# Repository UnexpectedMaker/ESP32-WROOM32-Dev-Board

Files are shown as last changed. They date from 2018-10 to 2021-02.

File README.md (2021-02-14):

# ESP32-WROOM32-Dev-Board
I decided a while back that I wanted to design, build and open source a WROOM32 ESP32 development board that was designed to plug a 2.1mm 5V power supply directly into it to drive high loads like hundreds of SK6812B's or 64x32 RGB Matrix Panels.

My revision 2 board works great, but uses a fairly expensive FT231XS FTDI USB Serial chip, so I thought I'd try to redesign it to use a cheap CH340C USB chip that has a built in oscillator to reduce parts.

My aim was to drive the CH340C from 3.3V and not 5V, and the data sheets suggests this is possible, but from my experience, it’s a terrible implementation.

So I have 2x CH340C folders…
Rev4 - CH340C driven from 3.3V
Rev5 - CH340C driven from 5V

Feel free to give the 3.3V version a whirl and if you can get ti working, please let me know how!

Anyway, this was just an experiment and it’s been a fun and frustrating journey, but I learnt a lot doing this and I’ve learnt stacks more since starting this project, so it’s time to let the files out into the wild so others can have a play with them. 

Enjoy!

# Support Unexpected Maker

I love designing, making and releasing my projects as open source. I do it because I believe it’s important to share knowledge and give back to the community, like many have done before me. It helps us all learn and grow.

That said, a lot of time, effort and finances have gone into designing and releasing these files, so please consider supporting me by buying some of my products:

https://unexpectedmaker.com/shop

https://www.tindie.com/stores/seonr/

Or by becoming a Patron:

https://www.patreon.com/unexpectedmaker

# Join my discord server
https://discord.com/invite/xAHpApP

# Unexpected Maker
https://unexpectedmaker.com

http://youtube.com/unexpectedmaker

http://twitter.com/unexpectedmaker

https://www.facebook.com/unexpectedmaker/

https://www.instagram.com/unexpectedmaker/

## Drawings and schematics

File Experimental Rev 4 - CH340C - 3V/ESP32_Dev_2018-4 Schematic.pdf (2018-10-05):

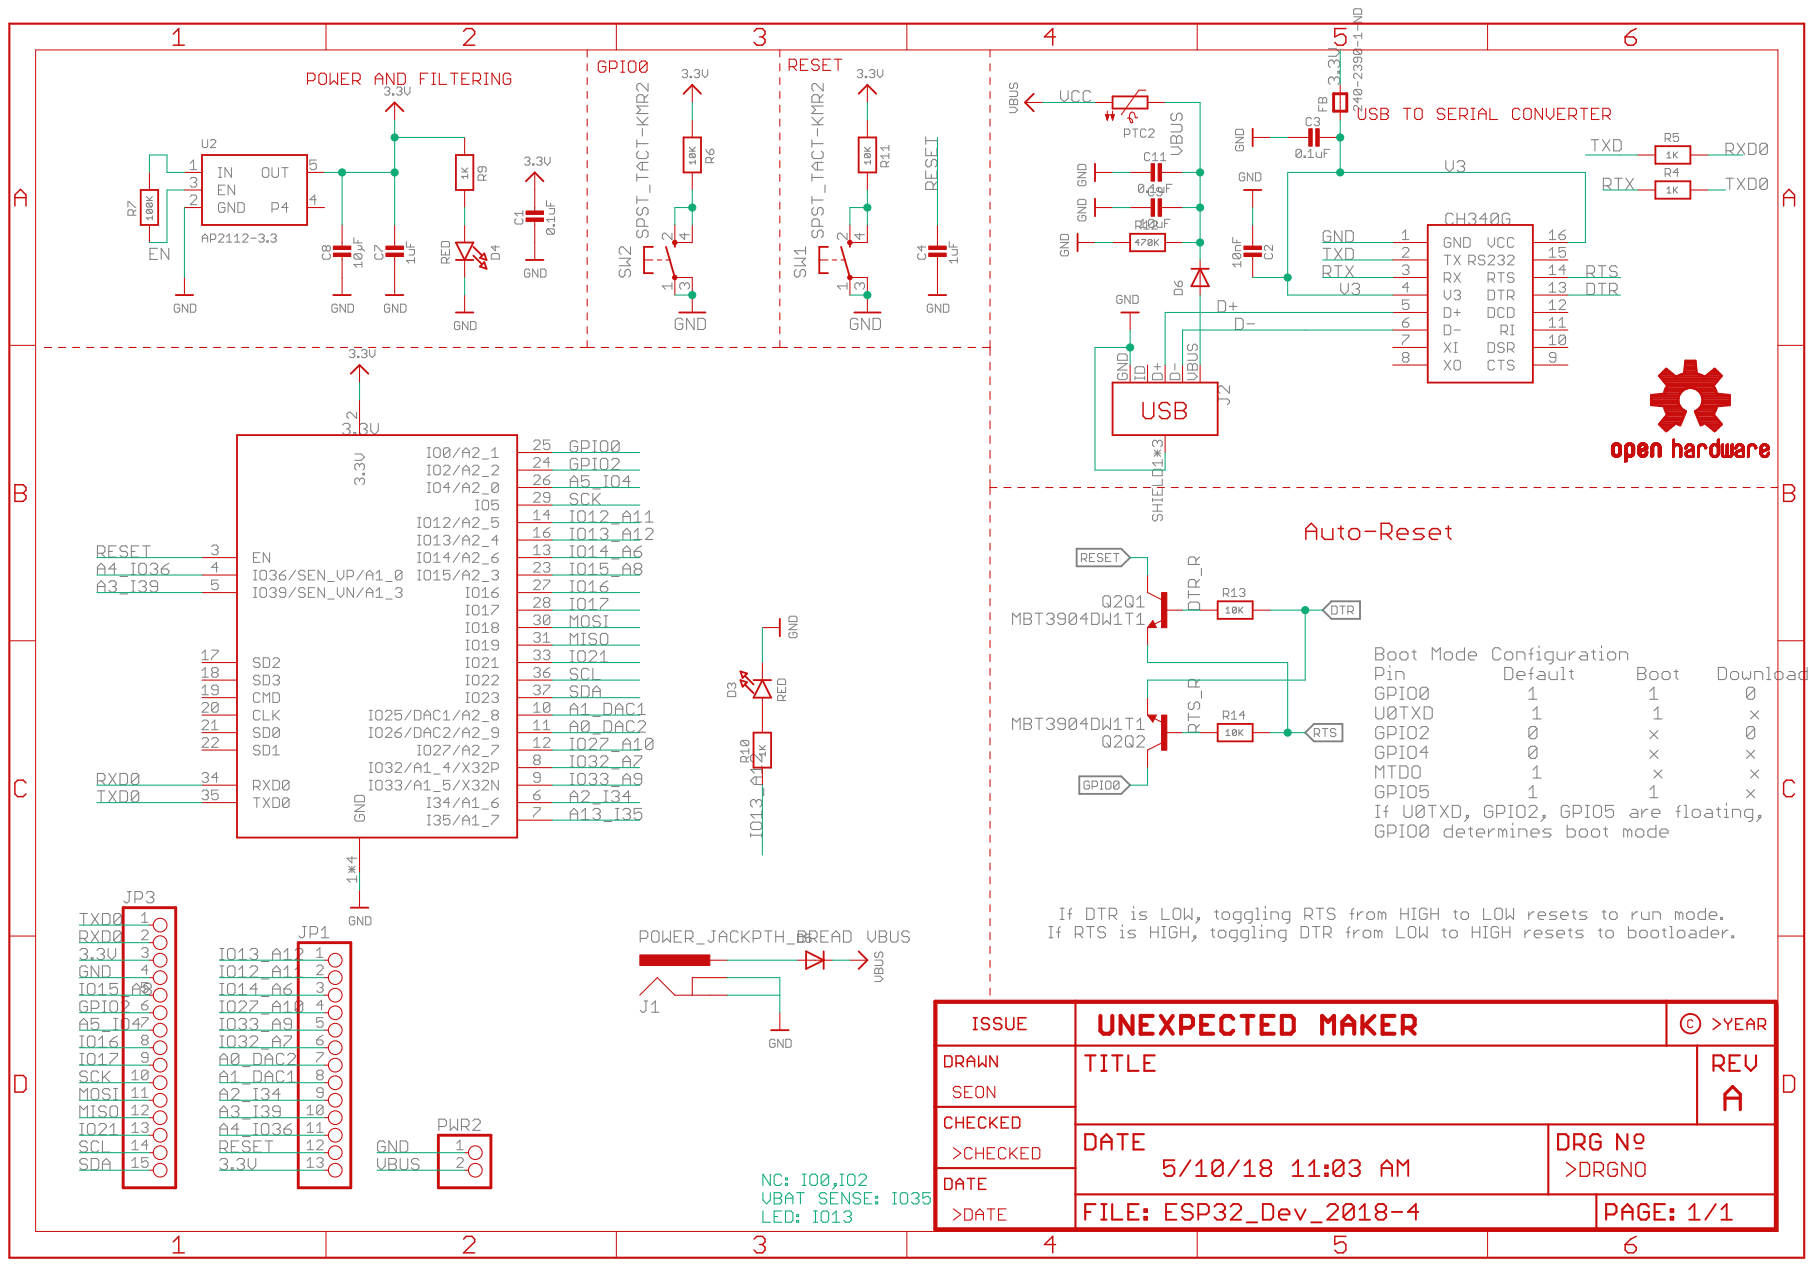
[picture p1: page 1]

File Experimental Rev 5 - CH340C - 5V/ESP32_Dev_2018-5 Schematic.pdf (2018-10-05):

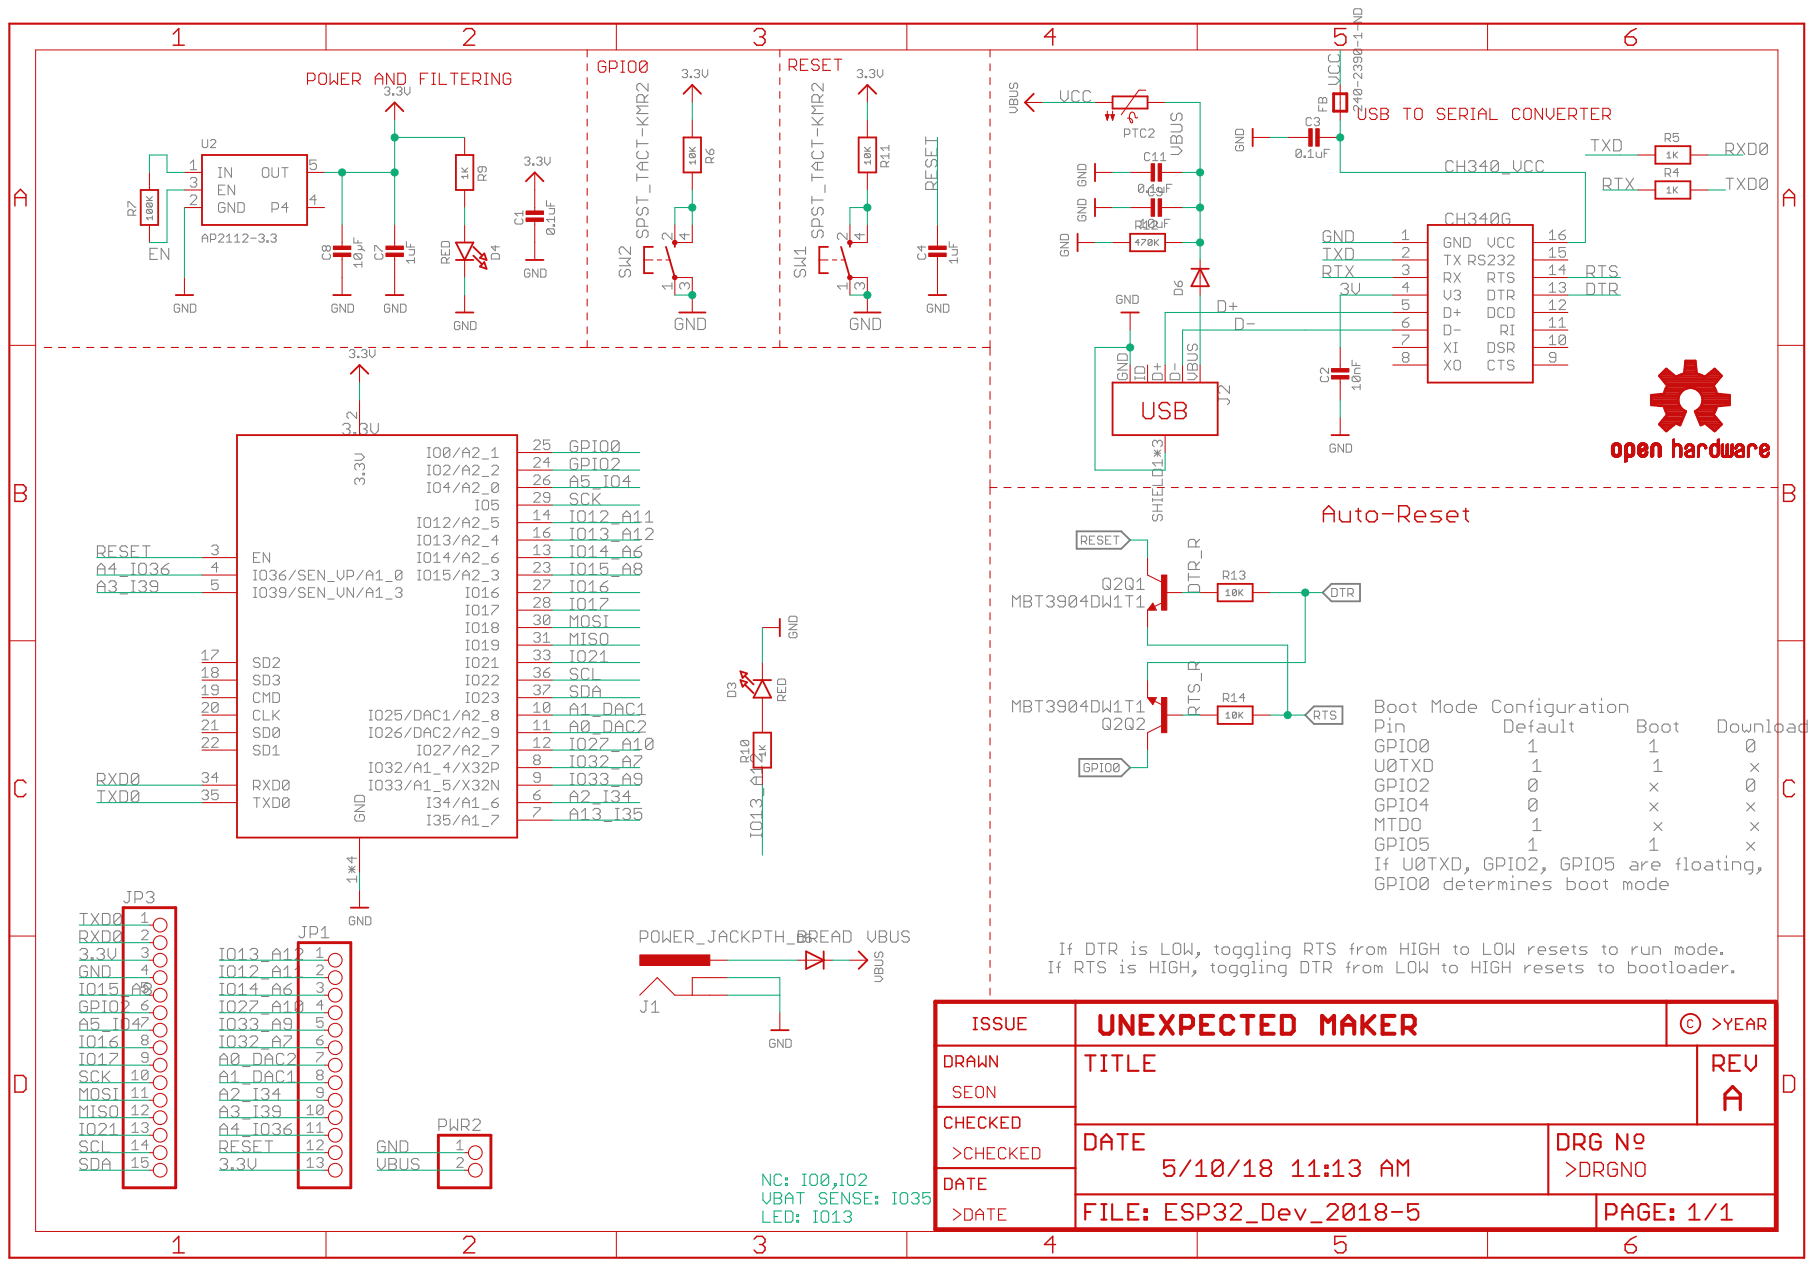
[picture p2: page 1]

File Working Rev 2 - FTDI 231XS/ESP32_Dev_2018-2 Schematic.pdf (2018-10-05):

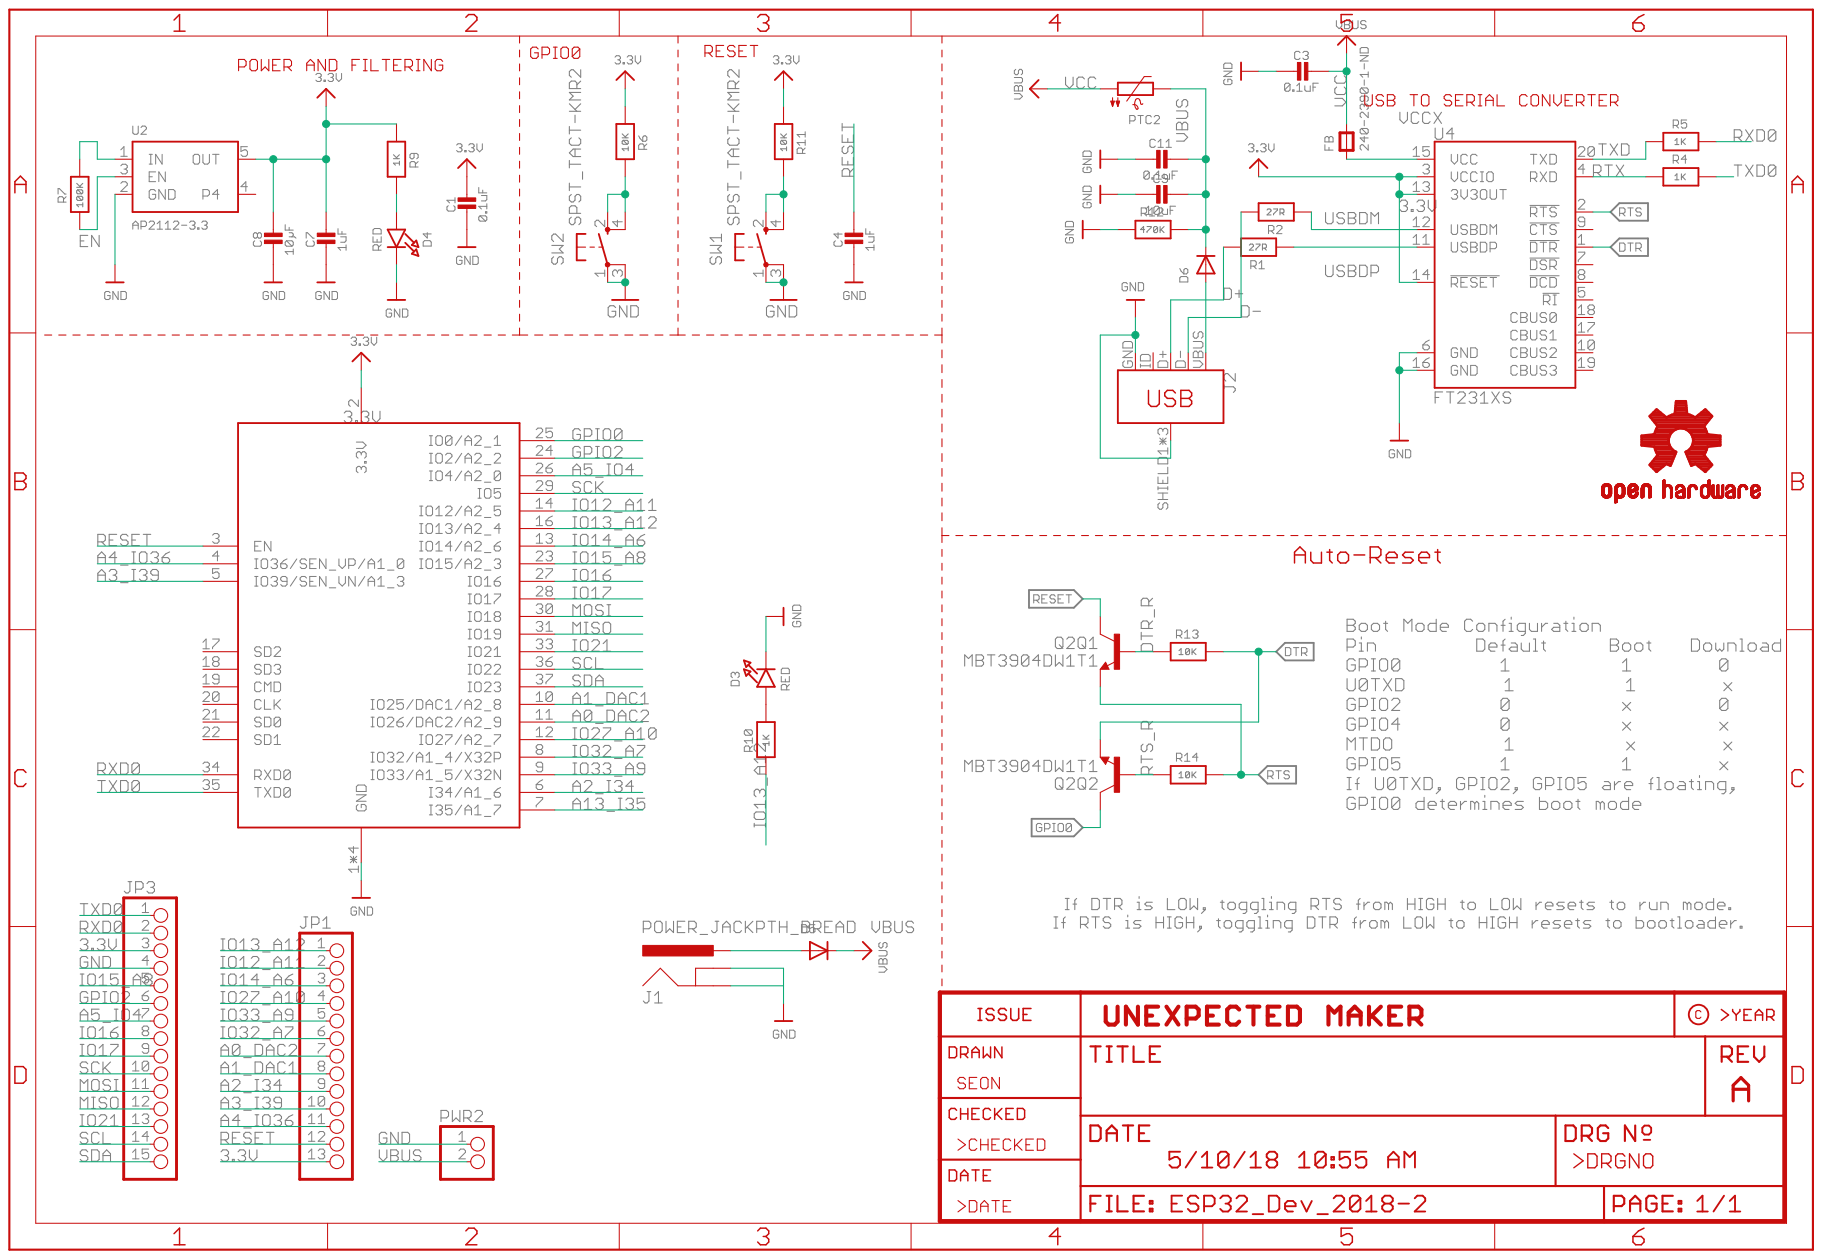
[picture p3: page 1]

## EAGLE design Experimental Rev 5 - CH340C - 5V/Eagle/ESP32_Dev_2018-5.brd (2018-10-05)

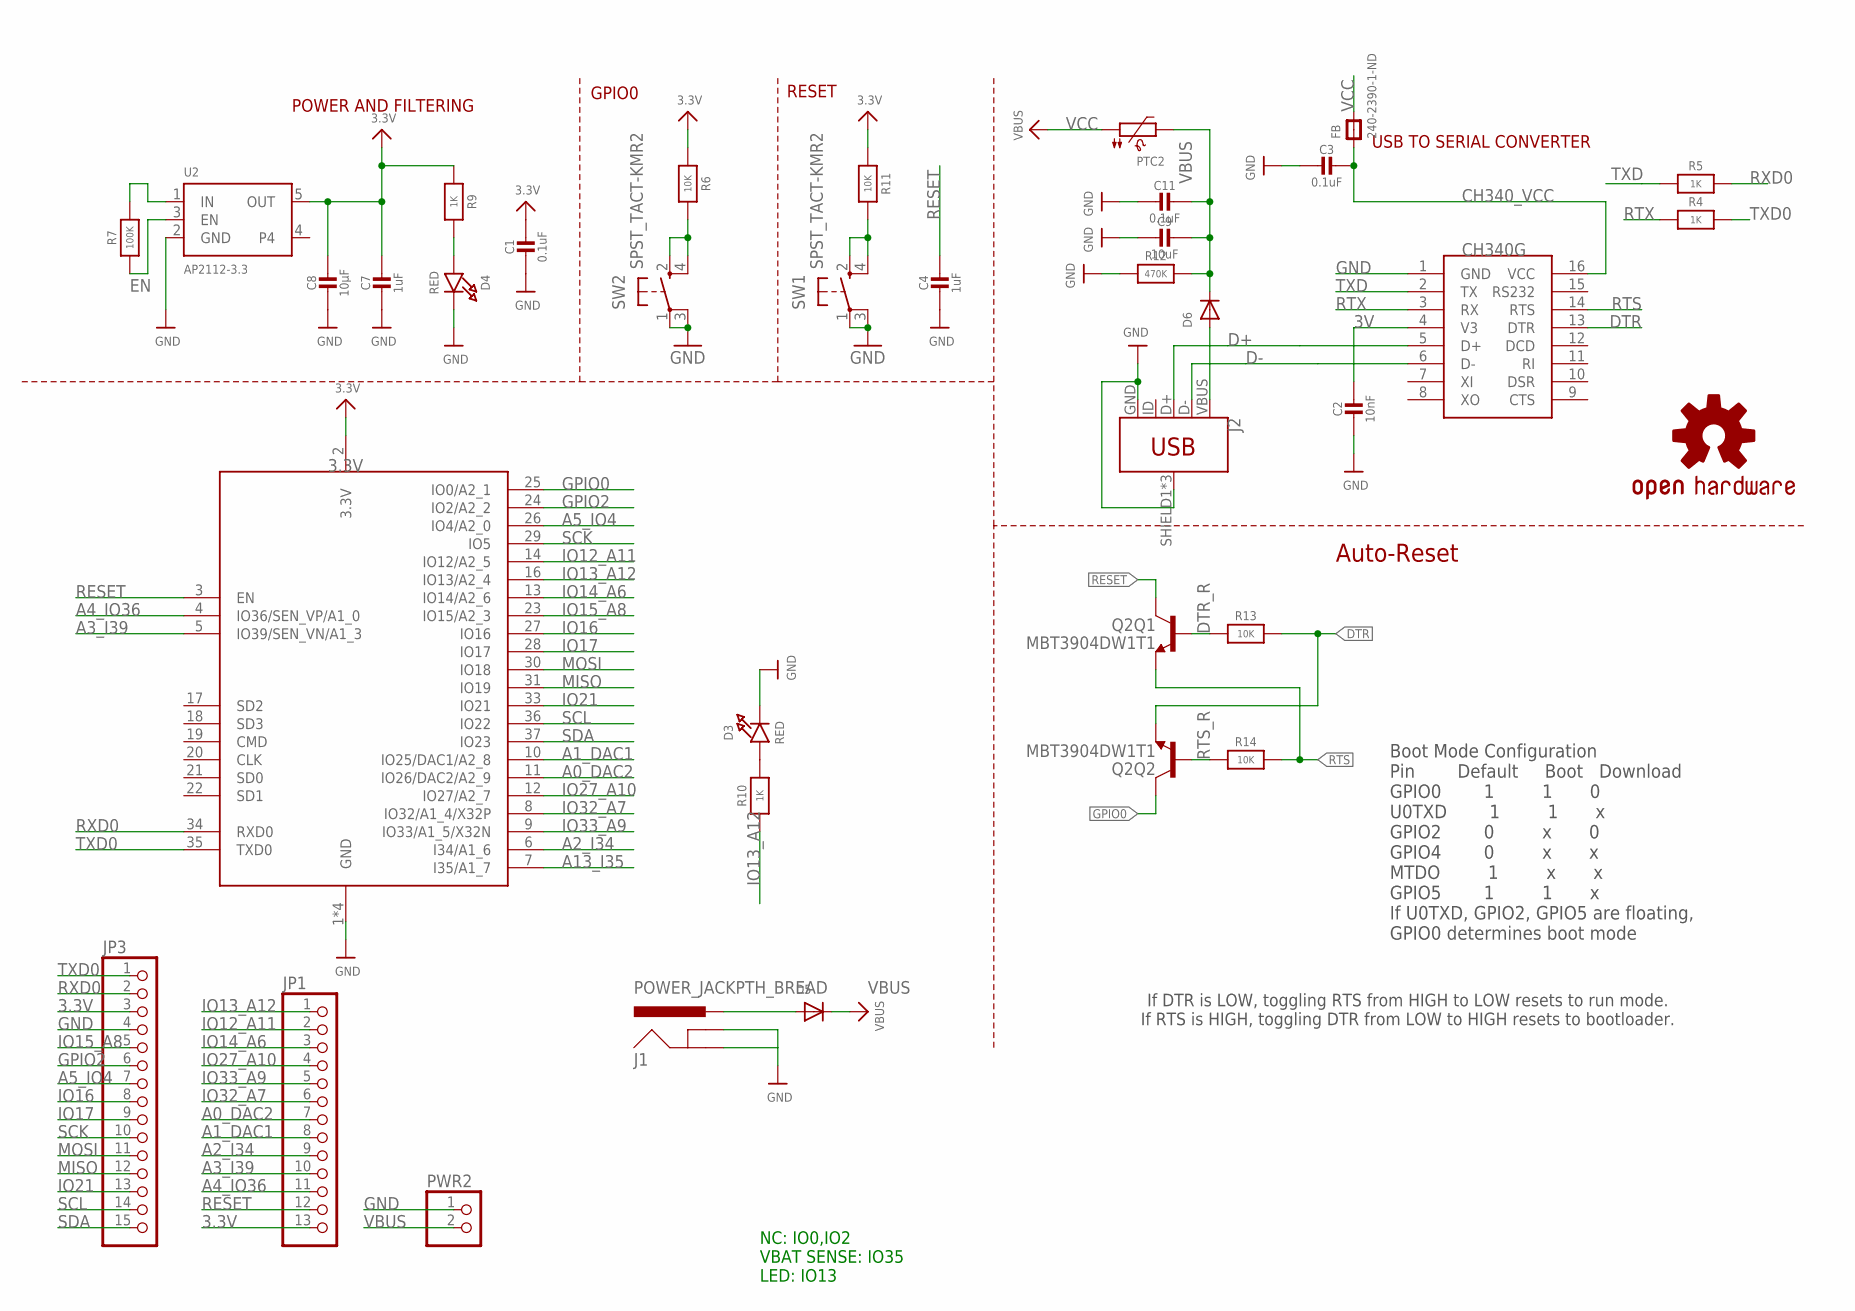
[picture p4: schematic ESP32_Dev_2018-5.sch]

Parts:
C1, C3, C11: 0.1uF; 0805-NO
C2: 10nF; 0805-NO
C4, C7: 1uF; 0805-NO
C8: 10µF; 0805-NO
C9: 10uF; 0805-NO
CH340C: CH340C; SOIC16
D3, D4: RED; CHIPLED_0805_NOOUTLINE
D5, D6: DIODESOD-123; SOD-123
FB: 240-2390-1-ND; _0805
J1: POWER_JACKPTH_BREAD; POWER_JACK_PTH_BREAD
J2: USB_MICRO-BREDUCED_PASTE; USB-B-MICRO-SMD_RED_PASTE
JP1: HEADER-1X13; 1X13_ROUND_70
JP3: HEADER-1X15; 1X15_ROUND_70
LOGO1: OSHW-LOGOM; OSHW-LOGO-M
PTC2: PTC1206; 1206
PWR2: HEADER-1X2ROUND; 1X02_ROUND
Q2: MBT3904DW1T1; SC70-6
R4, R5, R9, R10: 1K; 0805-NO
R6, R11, R13, R14: 10K; 0805-NO
R7: 100K; 0805-NO
R12: 470K; 0805-NO
SW1, SW2: SPST_TACT-KMR2; KMR2
U2: AP2112-3.3; SOT23-5
X2: ESP32_WROOM32; WROOM32

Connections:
3.3V: C1.1, C7.1, C8.1, JP1.13, JP3.3, R6.1, R9.1, R11.1, U2.5 (OUT), X2.2 (3.3V)
3V: C2.1, CH340C.4 (V3)
A0_DAC2: JP1.7, X2.11 (IO26/DAC2/A2_9)
A1_DAC1: JP1.8, X2.10 (IO25/DAC1/A2_8)
A2_I34: JP1.9, X2.6 (I34/A1_6)
A3_I39: JP1.10, X2.5 (IO39/SEN_VN/A1_3)
A4_IO36: JP1.11, X2.4 (IO36/SEN_VP/A1_0)
A5_IO4: JP3.7, X2.26 (IO4/A2_0)
A13_I35: X2.7 (I35/A1_7)
CH340_VCC: C3.1, CH340C.16 (VCC), FB.1
D+: CH340C.5 (D+), J2.D+
D-: CH340C.6 (D-), J2.D-
DTR: CH340C.13 (DTR), Q2.1 (E), R13.2
DTR_R: Q2.5 (B), R13.1
EN: R7.1, U2.3 (EN)
GND: C1.2, C2.2, C3.2, C4.2, C7.2, C8.2, C9.2, C11.2, CH340C.1 (GND), D3.C, D4.C, J1.GND, J1.GNDBREAK, J2.GND, J2.SHIELD1 (SHIELD), J2.SHIELD2 (SHIELD), J2.SHIELD3 (SHIELD), JP3.4, PWR2.1, R12.1, SW1.1, SW1.3 (P1), SW2.1, SW2.3 (P1), U2.2 (GND), X2.1 (GND), X2.15 (GND), X2.38 (GND), X2.P$1 (GND)
GPIO0: Q2.6 (C), R6.2, SW2.2 (S), SW2.4 (S1), X2.25 (IO0/A2_1)
GPIO2: JP3.6, X2.24 (IO2/A2_2)
IO12_A11: JP1.2, X2.14 (IO12/A2_5)
IO13_A12: JP1.1, R10.1, X2.16 (IO13/A2_4)
IO14_A6: JP1.3, X2.13 (IO14/A2_6)
IO15_A8: JP3.5, X2.23 (IO15/A2_3)
IO16: JP3.8, X2.27 (IO16)
IO17: JP3.9, X2.28 (IO17)
IO21: JP3.13, X2.33 (IO21)
IO27_A10: JP1.4, X2.12 (IO27/A2_7)
IO32_A7: JP1.6, X2.8 (IO32/A1_4/X32P)
IO33_A9: JP1.5, X2.9 (IO33/A1_5/X32N)
MISO: JP3.12, X2.31 (IO19)
MOSI: JP3.11, X2.30 (IO18)
unnamed: D6.A, J2.VBUS
unnamed: D3.A, R10.2
unnamed: D4.A, R9.2
RESET: C4.1, JP1.12, Q2.3 (C), R11.2, SW1.2 (S), SW1.4 (S1), X2.3 (EN)
RTS: CH340C.14 (RTS), Q2.4 (E), R14.2
RTS_R: Q2.2 (B), R14.1
RTX: CH340C.3 (RX), R4.1
RXD0: JP3.2, R5.2, X2.34 (RXD0)
SCK: JP3.10, X2.29 (IO5)
SCL: JP3.14, X2.36 (IO22)
SDA: JP3.15, X2.37 (IO23)
TXD: CH340C.2 (TX), R5.1
TXD0: JP3.1, R4.2, X2.35 (TXD0)
VBUS: C9.1, C11.1, D5.C, D6.C, PTC2.2, PWR2.2, R12.2
VBUS1: D5.A, J1.PWR
VCC: FB.2, PTC2.1, R7.2, U2.1 (IN)

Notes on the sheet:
POWER AND FILTERING
RESET
USB TO SERIAL CONVERTER
NC: IO0,IO2 VBAT SENSE: IO35 LED: IO13
Boot Mode Configuration Pin Default Boot Download GPIO0 1 1 0 U0TXD 1 1 x GPIO2 0 x 0 GPIO4 0 x x MTDO 1 x x GPIO5 1 1 x If U0TXD, GPIO2, GPIO5 are floating, GPIO0 determines boot mode
Auto-Reset
If DTR is LOW, toggling RTS from HIGH to LOW resets to run mode. If RTS is HIGH, toggling DTR from LOW to HIGH resets to bootloader.
GPIO0

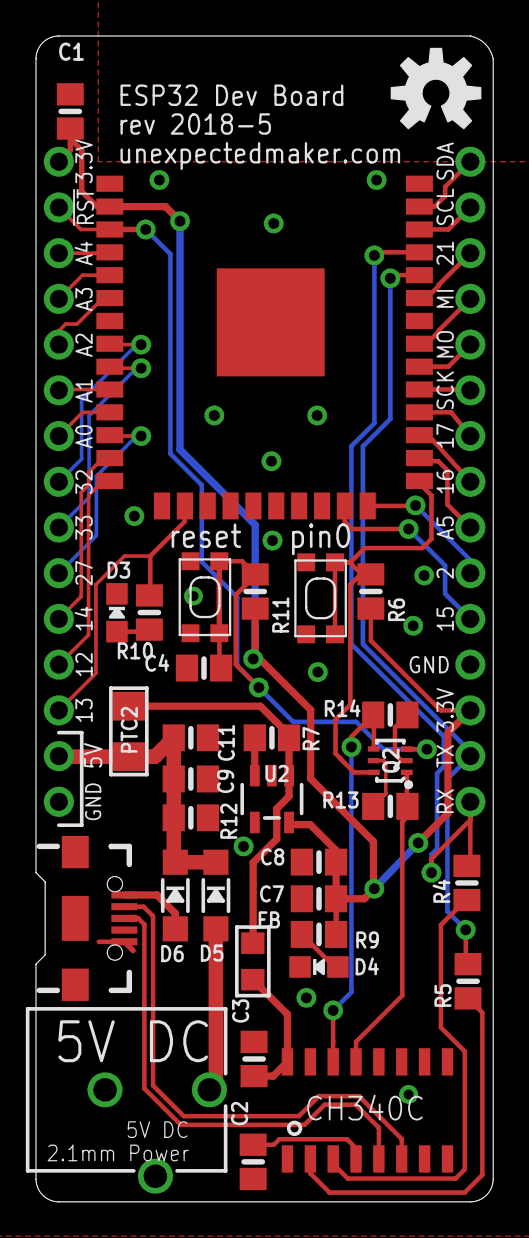
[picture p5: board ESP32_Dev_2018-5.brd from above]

Board: 2 copper layers, 25.4 x 64.8 mm, 37 parts (1 on the bottom side), 45 nets.

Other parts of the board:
LOGO2: OSHW-LOGOM; OSHW-LOGO-M

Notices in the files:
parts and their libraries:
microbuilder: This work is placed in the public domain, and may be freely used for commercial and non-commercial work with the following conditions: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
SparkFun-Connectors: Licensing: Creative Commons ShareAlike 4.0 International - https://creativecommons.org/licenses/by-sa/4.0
